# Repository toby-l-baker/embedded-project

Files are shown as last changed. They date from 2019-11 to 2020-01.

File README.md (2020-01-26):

# embedded-project
A semi-autonomous bike concept with the following goals
  1. Balance a model bicycle with a reaction flywheel.
  2. Drive the bike with a remote control and bluetooth.
  3. Implement state estimation to enable autonomous navigation.
  4. Setup a controller to send the bike to a target location.
  
## To see our final, integrated code base head to the Final Implementation folder in /software/apps

# Install
To use this repository first clone the directory. Following that run:
git submodule update --recursive --init

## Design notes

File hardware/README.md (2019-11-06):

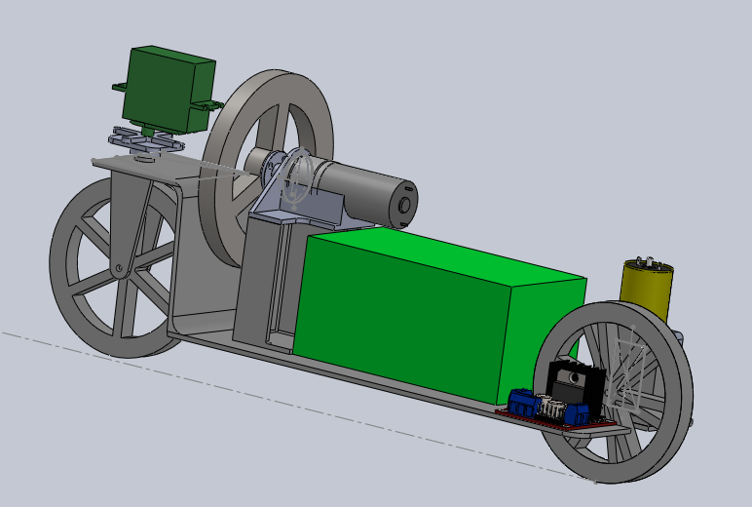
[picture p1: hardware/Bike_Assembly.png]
Bike

# Parts to Buy
## Driving Motor
https://www.amazon.com/dp/B071GX51N7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
## Flywheel Motor
https://www.pololu.com/product/4863
## Wheels
https://www.amazon.com/90-10mm-Black-Robot-Wheels/dp/B00T3MQG7M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
## Battery
https://www.amazon.com/TalentCell-Rechargeable-Amplifier-Multi-led-Indicator/dp/B00MHNQIR2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

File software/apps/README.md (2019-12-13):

# Instructions for fixing timer conflict: 
`ERROR 8 [NRF_ERROR_INVALID_STATE]`
### Edit line 25 of embedded-project/software/buckler/software/libraries/mpu9250/mpu9250.c to a new timer:
`static const nrf_drv_timer_t gyro_timer = NRFX_TIMER_INSTANCE(<X>);`
### Add the following definitions for the timer X in embedded-project/software/buckler/software/boards/buckler_revB/app_config.h:
`#define NRFX_TIMER<X>_ENABLED 1`<br />
`#define TIMER<X>_ENABLED 1`

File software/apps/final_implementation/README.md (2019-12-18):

# Final Implementation that was used on Demo Day

## Contents
1. accel_list: an adaptation of a linked list library found online used to store accelerometer readings to turn on brake lights
    * Author: Garey
2. bike_control_remote.py: bike_control is the file used from lab and bike_control_remote is an adaptation that uses the N64 remote joystick and various buttons to control the bike.
    * Author: Toby
3. board_params.h: contains all macros used throughout the code including pin numbers, constants etc.
4. control*: contains both the code used for estimation and control of the bike to it's desired location (app folder: self_driving)
   * Authors: Leo (Estimation), Carl (Control)
5. Madgwick*: a sensor fusion algorithm for the gyro and accelerometer of the mpu9250, this was sourced online and gave us reliable roll, pitch and yaw readings.
6. main: contains the state machine on the bike consisting of OFF, MANUAL and AUTONOMOUS modes as well as the BLE setup.
    * Author: Toby Baker
7. motor*: contains the functions to setup DC motors and write PWM values to them (app folder: motor_driver)
    * Author: Garey
8. mpu*: Contains all code relating to the mpu9250 including reading, filtering, SW interrupts.
    * Authors: Toby, Garey
9. servo_driver*: interface setting up and writing angles to the servo motor used for steering.
    * Authors: Carl, Leo
10. setup*: setup code for PWM channels used by each motors
    * Author: Garey
11. tail_lights*: code that controls the brake light and indicator lights on the bike, an essential safety feature of the sem-autonomous bike
    * Author: Garey
12. timer_module*: code for interfacing with the timer peripheral so that we could timestamp our angles, used for blinkers and estimation (as well as PID in balancing mode)
    * Author: Garey

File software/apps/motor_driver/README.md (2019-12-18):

# MOTOR DRIVER APP

## Contents
1. Initial app to interface with the motors

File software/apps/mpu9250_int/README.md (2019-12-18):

# MPU9250 App

## Contents
1. Initial app to interface with the MPU9250
2. Also initializes a timer to poll the sensor on SW interrupts

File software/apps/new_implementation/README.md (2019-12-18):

# Timers
MPU I2C:          1 <br />
Servo Motor PWM:  2 <br />
DC Motor PWM:     3 <br />
Timer Module:     4 <br />

## To Run project update repo: <br />
`git submodule update --init --recursive`
## Add the following macros to: <br /> 
`embedded-project/software/buckler/software/boards/buckler_revB/app_config.h`

`#define NRFX_TIMER0_ENABLED 1`<br />
`#define TIMER0_ENABLED 1`<br />
`#define NRFX_TIMER1_ENABLED 1`<br />
`#define TIMER1_ENABLED 1`<br />
`#define NRFX_TIMER2_ENABLED 1`<br />
`#define TIMER2_ENABLED 1`<br />
`#define NRFX_TIMER3_ENABLED 1`<br />
`#define TIMER3_ENABLED 1`<br />
`#define NRFX_TIMER4_ENABLED 1`<br />
`#define TIMER4_ENABLED 1`<br />

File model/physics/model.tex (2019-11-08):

\documentclass[11pt]{article}
\usepackage[utf8]{inputenc}
\usepackage[T1]{fontenc}
\usepackage[margin=0.75in]{geometry}
\usepackage{amsmath} 

\author{Léo Toulet, and I dont remember last names}
\date{Fall 2019}
\title{Flywheel stabilized self balancing bike - Physical modeling}

\begin{document}

\maketitle

\section{Lagrangian dynamics}

The objective of this document is to provide a physical model of a simple Bike system. Our objective is to to be able to balance such a bike even at low speeds, using a closed-loop flywheel to counter the action of gravity on the bike and maintain an upward position.
For this purpose, we define a simple model of our bike system, consisting of two main parts. 
\begin{itemize}
	\item The bike structure, containing the frame, battery, Buckler and wheels
	\item The Motor+Flywheel assembly, that actually balances the bike
\end{itemize}

\subsection{Definitions}

We define the intrinsic parameters of the bike structure as its mass $m_b$, its moment of inertia about its rotation axis (i.e. is the ground) $I_b$ and the height of its center of gravity $L_b$. Similarly, we define the mass of the motor,flywheel assembly to be $m_w$, its distance to the ground to be $L_w$ and the moment of inertia of the wheel around its rotation axis to be $I_w$. As far as the rotational motion of the bike+flywheel+motor structure is concerned, we consider the \{flywheel+motor\} to be a point. 

To define the Lagrangian of the system, we also need to define the generalized coordinates, which in our case are simple $\alpha$, the angle the bike makes with the vertical, and $\theta$, the angle the flywheel makes to some arbitrary reference point. We therefore have $$ q = [\alpha, \theta]$$. Finally, we define $F$ to be the generalized forces applied to our system, and we assume that \textit{there are no non-conservative forces}

%Insert diagram here

\subsection{Lagrangian}

Using our previous definitions, we define the Lagrangian function to be the following quantity $L(q,\dot{q}) = E(q, \dot{q}) - V(q, \dot{q})$. Here, E is the kinetic energy of the system and V is its potential energy. The Lagrangian satisfies the following equation: satisfies:

$$ \frac{d}{dt}\frac{\partial L}{\partial \dot{q}} - \frac{\partial L}{\partial q} = F$$ 

\subsection{Energies}

We will begin with the the potential energy. The only potential energy applied on the system comes from the weight. Therefore, we have $V(q, \dot{q}) = (m_w L_w + m_b L_b)g\sin(\alpha)$. Here, we will only consider small inclinations of the bike $\alpha << \pi/6$, and we can reasonably make the approximation that the sine is equal to its argument, transforming our potential energy into 

$$V(q, \dot{q}) = (m_w L_w + m_b L_b)g\alpha$$

The kinetic energy has three terms. The first two account for the kinetic energy of the global rotation of the system around the ground axis. The last term accounts for the rotation of the wheel around the motor axis.

$$E(q, \dot{q}) = \frac{1}{2}\left[I_p \dot{\alpha}^2 + m_w L_w^2 \dot{\alpha}^2 + I_w \dot{\theta}^2)\right]$$

Finally, $F$ is the vector of generalized forces that apply on the system, which in our case is simply defined as:

$$F = [-I_w \ddot{\alpha}, \tau - I_w \ddot{\theta}]$$

\subsection{System dynamics}

Working through the differentiation, we arrive at the following coupled equations: 

$$I_s \ddot{\alpha} + I_w\ddot{\theta} = \tau_\alpha \alpha$$
$$I_w(\ddot{\alpha} + \ddot{\theta}) = \tau$$

Where $\tau_\alpha  = (m_b L_b + m_w L_w)g$ and $ I_s= I_b + m_w*L_w^2$

\section{System specifications}

Using the previous coupled equations, we want to find the minimum motor and flywheel specifications for our self-balancing bike to work. To do that, we will make a couple of assumptions:

\begin{center}
\begin{tabular}{|c|rl|}
\hline
Variable & Value & Unit \\
\hline
\hline

$L_w$ & $10$ & $cm$ \\
$L_b$ & $5$ & $cm$ \\
$m_w$ & $600$ & $g$ \\
$m_b$ & $1000$ & $g$ \\
$I_b$ & $5 10^{-3}$ & $kgm^2$ \\
$I_w$ & $9 10^{-5}$ & $kgm^2$ \\
\hline
\end{tabular}
\end{center}

Using those vales, we get $\tau_\alpha = 3 Nm$ and $I_s = 1.1 10^{-2} kgm^2$. Assuming we want alpha to remain within 4 degrees of the vertical, we define $\alpha_{max} = 0.07$ rad.

\subsection{Flywheel motor}

The dynamics equations can be coupled to give:

$$\ddot{\alpha} = \frac{\tau_\alpha \alpha - \tau}{I_s + I_w}$$

Correcting an imbalance means correcting the sign of $\ddot{\alpha}$ to make it opposite to that of $\alpha$. That is, if we want our system to be able to be able to correct positioning errors, we want:

$$|\tau| > |\tau_\alpha \alpha_{max}|$$

i.e. :

$$|\tau| > 0.2 Nm$$

\subsection{Flywheel moment of inertia}

\end{document}

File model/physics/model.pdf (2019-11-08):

## Flywheel stabilized self balancing bike - Physical modeling

Léo Toulet, and I dont remember last names

Fall 2019

## 1 Lagrangian dynamics

The objective of this document is to provide a physical model of a simple Bike system. Our objective is to to be able to balance such a bike even at low speeds, using a closed-loop ywheel to counter the action of gravity on the bike and maintain an upward position. For this purpose, we dene a simple model of our bike system, consisting of two main parts.

- The bike structure, containing the frame, battery, Buckler and wheels
- The Motor+Flywheel assembly, that actually balances the bike

1.1 Denitions

We dene the intrinsic parameters of the bike structure as its mass mb, its moment of inertia about its rotation axis (i.e. is the ground) Ib and the height of its center of gravity Lb. Similarly, we dene the mass of the motor,ywheel assembly to be mw, its distance to the ground to be Lw and the moment of inertia of the wheel around its rotation axis to be Iw. As far as the rotational motion of the bike+ywheel+motor structure is concerned, we consider the {ywheel+motor} to be a point.
To dene the Lagrangian of the system, we also need to dene the generalized coordinates, which in our case are simple α, the angle the bike makes with the vertical, and θ, the angle the ywheel makes to some arbitrary reference point. We therefore have

q = [α, θ]

. Finally, we dene F to be the generalized forces applied to our system, and we assume that there are no non-conservative forces

1.2 Lagrangian

Using our previous denitions, we dene the Lagrangian function to be the following quantity L(q, q˙) = E(q, q˙) − V (q, q˙). Here, E is the kinetic energy of the system and V is its potential energy. The Lagrangian satises the following equation: satises:

d
dt

∂L
∂q˙

−

∂L
∂q = F

1.3 Energies

We will begin with the the potential energy. The only potential energy applied on the system comes from the weight. Therefore, we have V (q, q˙) = (mwLw + mbLb)g sin(α). Here, we will only consider small inclinations of the bike α << π/6, and we can reasonably make the approximation that the sine is equal to its argument, transforming our potential energy into

1

V (q, q˙) = (mwLw + mbLb)gα

The kinetic energy has three terms. The rst two account for the kinetic energy of the global rotation of the system around the ground axis. The last term accounts for the rotation of the wheel around the motor axis.

E(q, q˙) = 1
2

h
Ipα˙

2 + mwL

2
wα˙

2 + Iw

˙θ
2
)

i

Finally, F is the vector of generalized forces that apply on the system, which in our case is simply dened as:

F = [−Iwα, τ ¨ − Iw

¨θ]

1.4 System dynamics

Working through the dierentiation, we arrive at the following coupled equations:

Isα¨ + Iw

¨θ = ταα

Iw(¨α + ¨θ) = τ

Where τα = (mbLb + mwLw)g and Is = Ib + mw ∗ L

2
w

## 2 System specications

Using the previous coupled equations, we want to nd the minimum motor and ywheel specications for our self-balancing bike to work. To do that, we will make a couple of assumptions:

Variable | Value Unit
Lw Lb mw mb Ib Iw | 10 cm 5 cm 600 g 1000 g 510⁻³ kgm² 910⁻⁵ kgm²

Using those vales, we get τα = 3Nm and Is = 1.110⁻²kgm² . Assuming we want alpha to remain within 4 degrees of the vertical, we dene αmax = 0.07 rad.

2.1 Flywheel motor

The dynamics equations can be coupled to give:

α¨ =

ταα − τ
Is + Iw
Correcting an imbalance means correcting the sign of α¨ to make it opposite to that of α. That is, if we want our system to be able to be able to correct positioning errors, we want:
|τ | > |τααmax|

i.e. :

|τ | > 0.2Nm

2

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

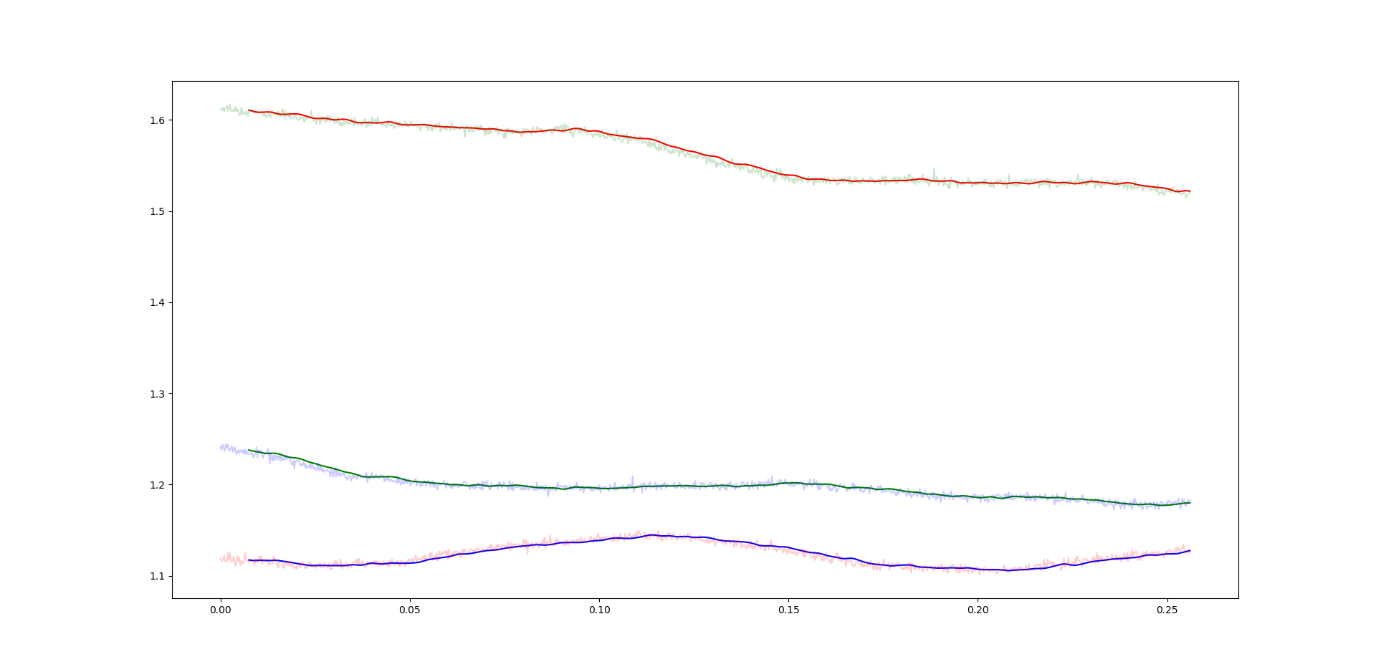
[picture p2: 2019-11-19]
software/apps/signal_processing/XYZ_Filtered.png

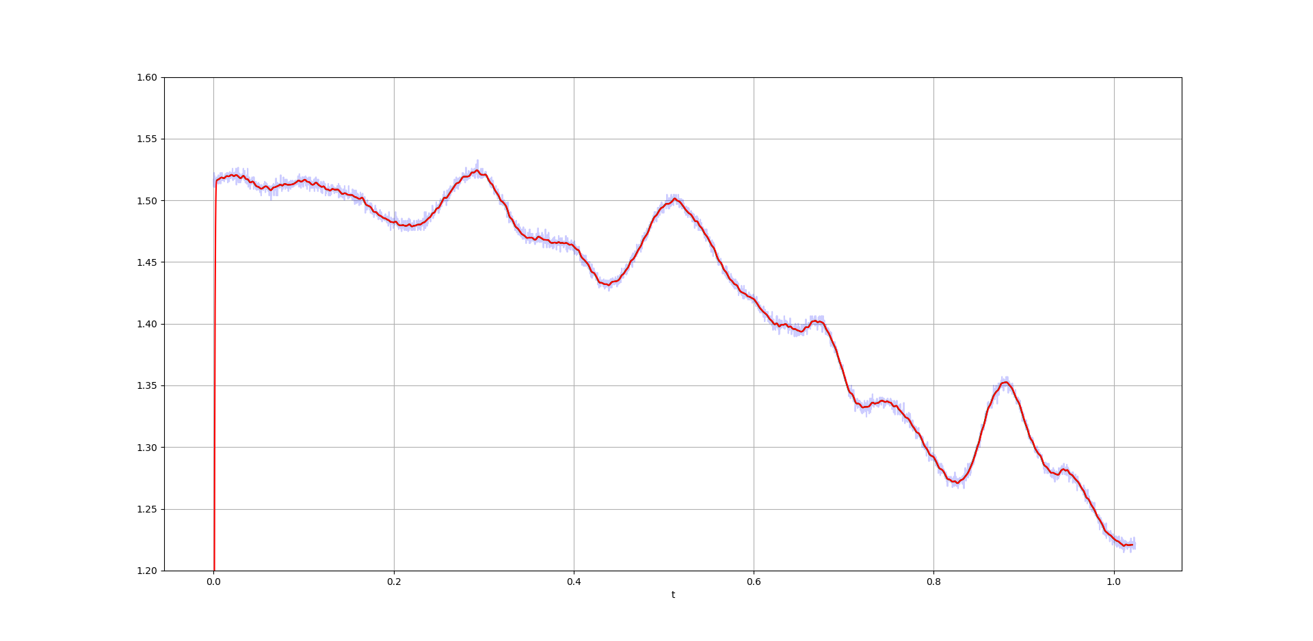
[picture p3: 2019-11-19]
software/apps/signal_processing/X_Filtered.png

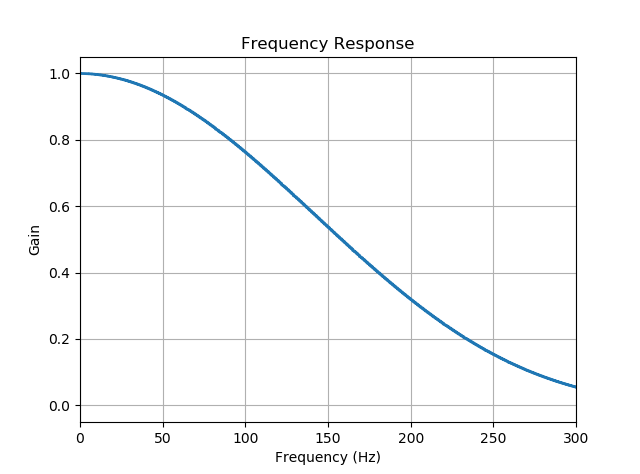
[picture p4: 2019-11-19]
software/apps/signal_processing/Freq_Response.png

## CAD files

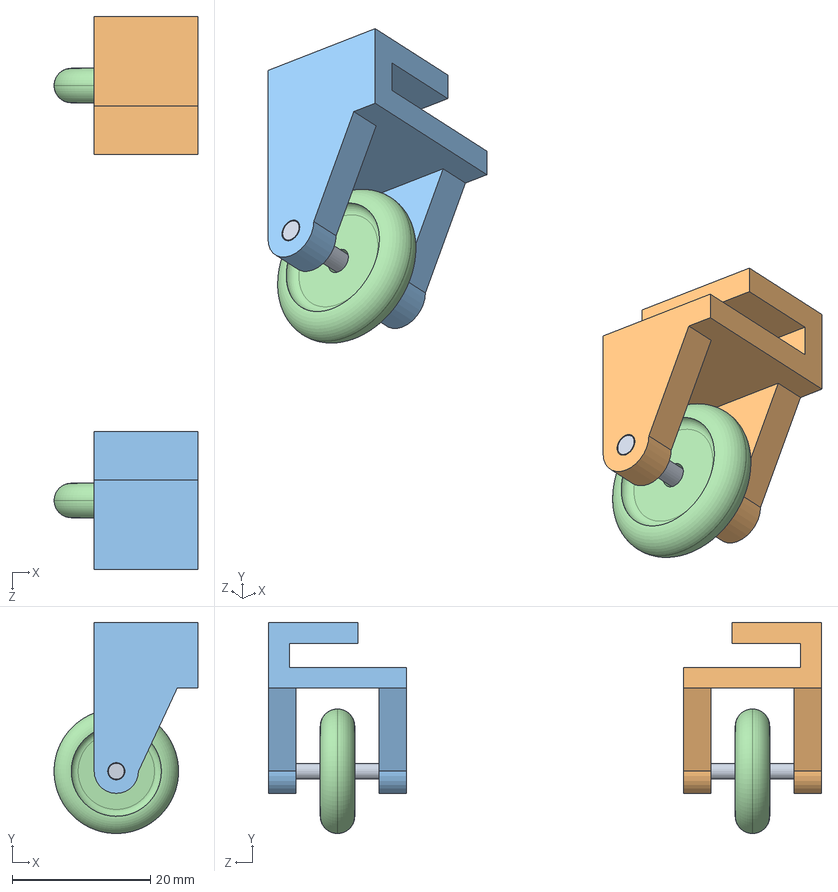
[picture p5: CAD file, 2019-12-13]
hardware/Caster_Assembly_Left.SLDASM
20.8 x 30.5 x 80.0 mm
Caster_Wheel_Axle x 2
Caster_Wheel_Holder_Mirror
Caster_Wheel_Holder
Caster_Wheel x 2

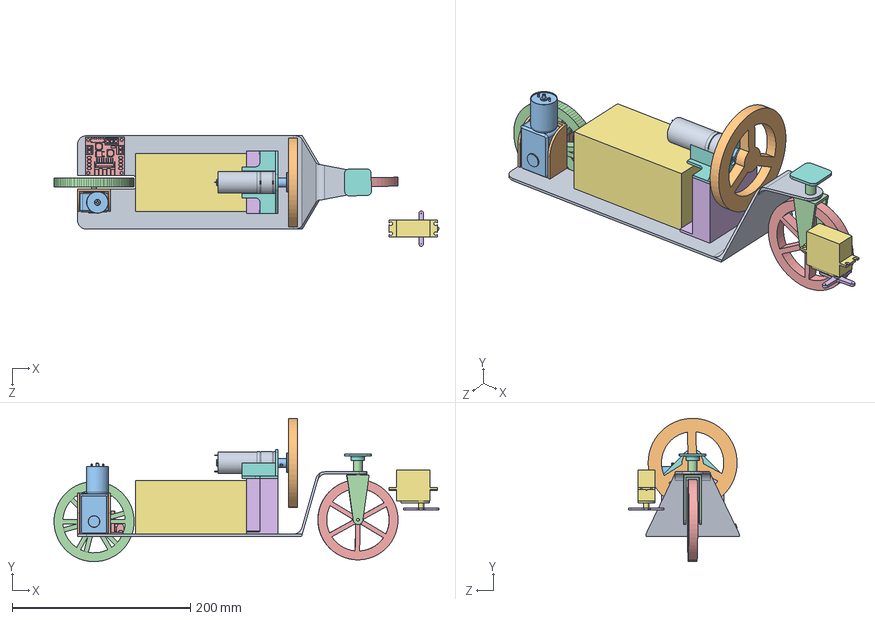
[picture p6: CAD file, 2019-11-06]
hardware/Bike_Assembly.SLDASM
432.5 x 160.9 x 124.4 mm
Bike_Base
Drive_Motor_Holder
Drive_Motor
Basic_Wheel_Model (1) x 2
L298N
Flywheel_Motor_Holder_Base
Buckler_Place_Holder
Flywheel_Motor_Holder
Flywheel_Motor
Flywheel
Flywheel_coupler
Front_Fork
Basic_Wheel_Model
Servo_Plate
servo_motor
Servo_Front_Fork_Connector

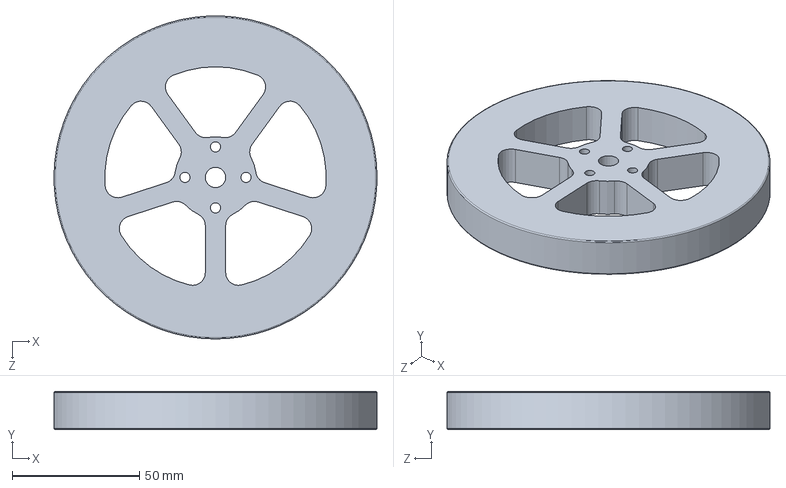
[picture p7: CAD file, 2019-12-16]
hardware/Final_Flywheel.SLDPRT
127.0 x 15.0 x 126.9 mm

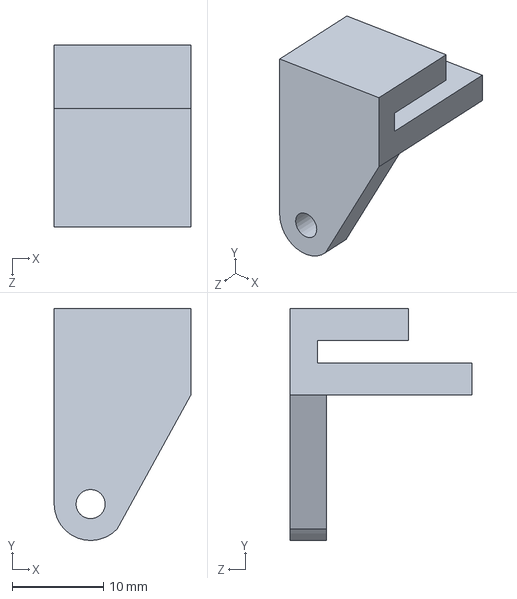
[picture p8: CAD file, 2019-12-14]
hardware/Caster_Wheel_Holder.SLDPRT
15.0 x 25.5 x 20.0 mm

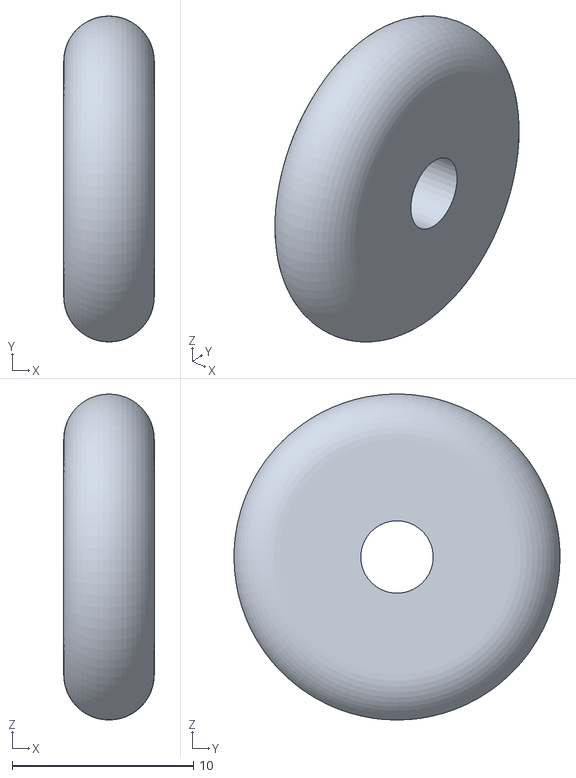
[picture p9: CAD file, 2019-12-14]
hardware/Manufacturing Files/Caster_Wheel.STL
5.00 x 18.0 x 18.0

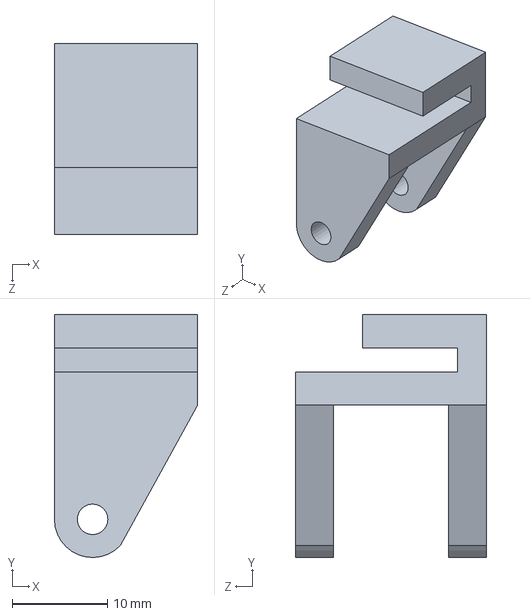
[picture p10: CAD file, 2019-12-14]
hardware/Caster_Wheel_Holder_Mirror.SLDPRT
15.0 x 25.5 x 20.0 mm

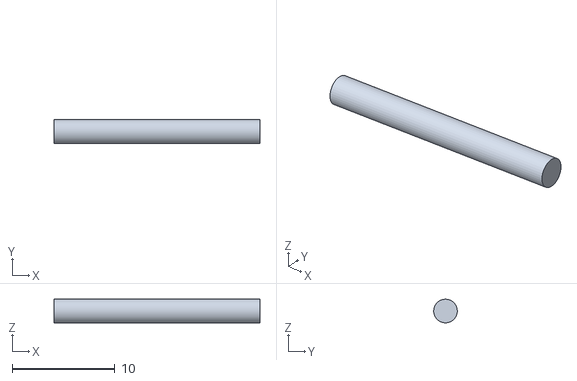
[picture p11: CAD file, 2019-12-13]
hardware/Manufacturing Files/Caster_Wheel_Axle.STL
20.0 x 2.30 x 2.30

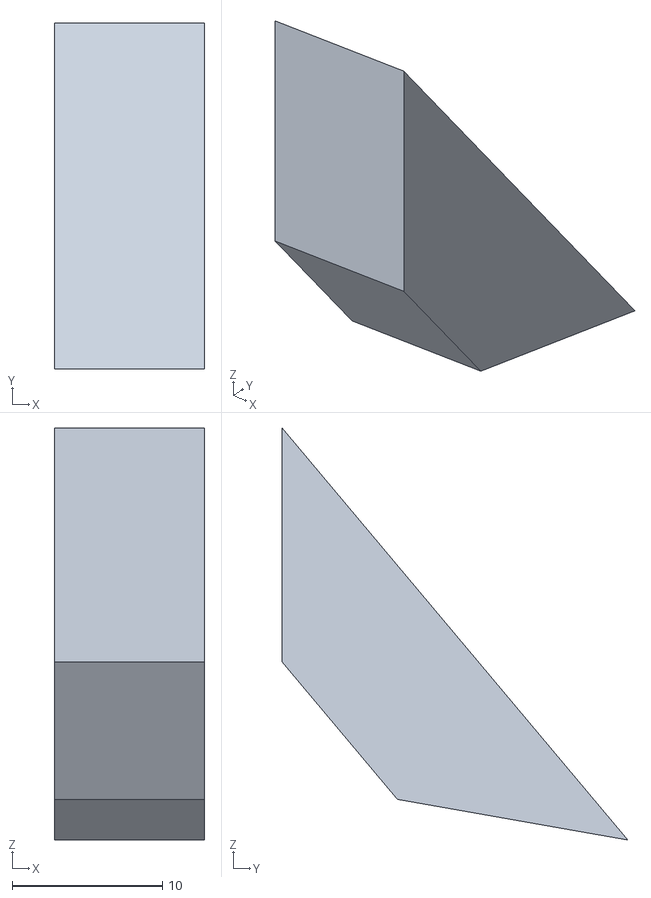
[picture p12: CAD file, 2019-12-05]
hardware/Manufacturing Files/Upper_Gusset.STL
10.0 x 23.0 x 27.4

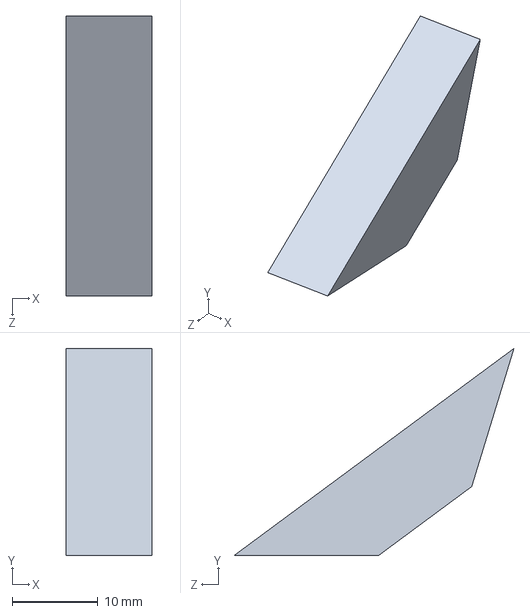
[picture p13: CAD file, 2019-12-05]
hardware/Lower_Gusset.SLDPRT
10.0 x 24.1 x 32.6 mm

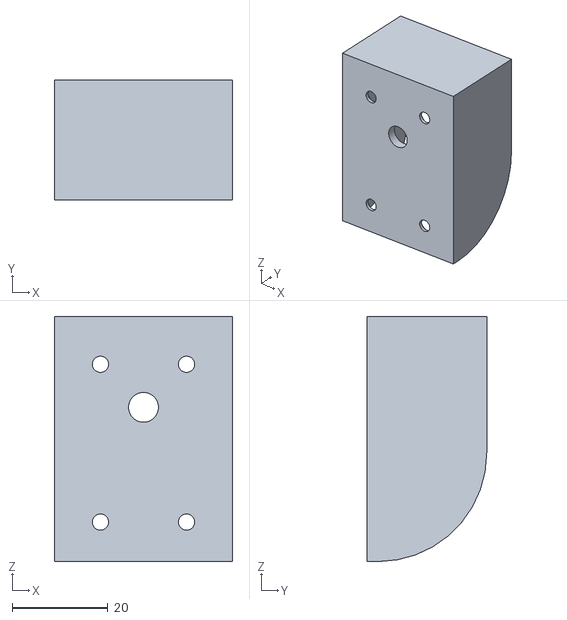
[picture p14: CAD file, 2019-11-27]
hardware/Manufacturing Files/Drive_Motor_Holder.stl
37.2 x 25.0 x 51.2

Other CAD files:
hardware/Manufacturing Files/Final_Flywheel.stl
hardware/Caster_Wheel.SLDPRT
hardware/Manufacturing Files/Caster_Wheel_Holder.STL
hardware/Manufacturing Files/Caster_Wheel_Holder_Mirror.STL
hardware/Caster_Wheel_Axle.SLDPRT
hardware/Manufacturing Files/Lower_Gusset.STL
hardware/Upper_Gusset.SLDPRT
hardware/Flywheel_3DPrinter.SLDPRT
hardware/Basic_Wheel_Model.SLDPRT
hardware/Bike_Base.SLDPRT
hardware/Buckler_Place_Holder.SLDPRT
hardware/Drive_Motor.SLDPRT
hardware/Drive_Motor_Holder.SLDPRT
hardware/Flattened_Base.DXF
hardware/Flattened_Base.SLDPRT
hardware/Flywheel.SLDPRT
hardware/Flywheel_Motor.SLDPRT
hardware/Flywheel_Motor_Holder.SLDPRT
hardware/Flywheel_Motor_Holder_Base.SLDPRT
hardware/Flywheel_coupler.SLDPRT
hardware/Front_Fork.SLDPRT
hardware/L298N.SLDPRT
hardware/Manufacturing Files/Bike_Base.stl
hardware/Manufacturing Files/Flywheel_3DPrinter.stl
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

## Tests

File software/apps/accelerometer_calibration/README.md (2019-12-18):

# Accelerometer Calibration App
### Author: Toby Baker

## Contents
1. slist: an implementation of a linked list found online used to store 30 readings which will then be passed to an FIR filter
2. virtual_timer libraries: virtual timer linked list from lab to get regular samples from the accelerometer
3. main: contains an implementation of an FIR filter applied to each channel of the analog accelerometer
4. Various .txt files containing the output of the analog accelerometer

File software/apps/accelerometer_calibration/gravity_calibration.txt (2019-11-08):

Vcc = ?

+1g Z: 1.8040 V
-1g Z: 1.0224 V
0g Z: 1.3950 V

V(+1g) = z_bias + 1g * z_gain
V(-1g) = z_bias - 1g * z_gain

2.8264 = 2*z_bias
z_bias = 1.4132 V
z_gain = 1.8040 - 1.4132 = 0.3908 V/g

+1g Y: 1.7878 V
-1g Y: 1.0140 V
0g Y: 1.4075 V

y_bias = 1.4009 V
y_gain = 0.3869 V/g

+1g X: 1,7840 V
-1g X: 1.0242 V
0g X: 1.3830 V

x_bias = 1.4041 V
x_gain = 0.3799 V/g

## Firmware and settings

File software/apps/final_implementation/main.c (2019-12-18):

/*** Final Implementation of the Semi-Autonomous Bike Demo ***/

#include "setup.h" // includes all libraries we use

/* Function for printing the state that the bike is in for debugging ***/
void print_state(bike_states current_state){
	switch(current_state){

  	case OFF: {
  		printf("Off\n");
  		break;
    }

    case MANUAL: {
  		printf("Manual\n");
  		break;
    }

    case AUTONOMOUS: {
  		printf("Autonomous\n");
  		break;
    }

  }
}

int main(void) {
	float x, y, heading, turn_auto = 0.0; // variables for the current x, y and heading of the bike
	bool destination_set = false;

  // setup the board
  initialize_buckler();
  // setup BLE
  init_ble_receiver();

	// setup the servo
	struct servo * front = create_servo(SERVO_PIN, PWM_CHANNEL_0);
  initialize_servo_motor_pwm(front);

  // setup the drive motor and flywheel
	struct dc_motor * drive = create_dc_motor(DRIVE_PIN_ENABLE, DRIVE_PIN_IN1, DRIVE_PIN_IN2, DRIVE_MOTOR_CHANNEL);
  int8_t direction = STOP; // direction for the drive motor
  struct dc_motor * flywheel = create_dc_motor(FLYWHEEL_PIN_ENABLE, FLYWHEEL_PIN_IN1, FLYWHEEL_PIN_IN2, FlYWHEEL_MOTOR_CHANNEL);
	initialize_dc_motor_pwm(drive, flywheel);

  // setup the mpu9250 software interrupts and the sensor (I2C etc.)
  bool ble = true; // to avoid double initializing app_timer
  init_mpu9250_timer(IMU_TIMER_REFRESH_RATE, ble);
  init_mpu9250();

  // setup the angles struct - struct in mpu.h
  struct angles_t * angles = malloc(sizeof(angles_t));
  angles->heading = 0.0;

  // setup tail lights (initializes the display)
  init_tail_lights();

  // initialise the tracking by giving it a pointer to drive motor, servo motor and the angles struct
  init_tracking(drive, front, angles);

  // begin tracking the bikes position
  start_tracking();

	// loop forever, running state machine
  printf("Entering Main\n");

  // used to print less often
  int i = 0;

	while (1) {
    // update the angles struct (internally checks if the timer has fired)
    update_angles(angles);

    // update the blinkers on the LCD screen
    update_lights(angles);

    /*** STATE MACHINE ***/
    switch(bike_state) { // state transitions handled by the callback function for BLE events
      /*** BIKE OFF ***/
      case OFF: {
        print_state(bike_state);
        break; // each case needs to end with break!
      }

      /*** MANUAL CONTROL OF THE BIKE ***/
      case MANUAL: {
        print_state(bike_state);

        // set servo angle to the user defined angle (from joystick)
        set_servo_angle(front, (float) turn_angle);

        // set the bikes direction based off the drive_speed
        if (drive_speed == 0){
          direction = STOP;
        } else if (drive_speed > 0) {
        	direction = FORWARD;
        } else {
          direction = REVERSE;
        }
        // send values to the drive_motor
        set_dc_motor_direction(drive, direction);
    	  set_dc_motor_pwm(drive, drive_speed);

        // print debug info every 20 loops
        if (i++ % 20 == 0) {
          printf("%f\n", angles->time_stamp);
        }
        break;
      }

      /*** AUTONOMOUS CONTROL OF THE BIKE ***/
      case AUTONOMOUS: {
        print_state(bike_state);
        // Wait until our path is defined or we have accomplished our goal
        if ((path_angle_received == false) || (path_len_received == false) || (nav_complete == true)) {
          direction = STOP;
          drive_speed = 0;
          turn_auto = 0;
          // printf("IM DOING NOTHING: nav %d, len: %d, ang: %d\n", nav_complete, path_len_received, path_angle_received);
          // ensures the gyro is reset before we start navigation
          mpu9250_stop_gyro_integration();
        } else {
          /*** GET TO OUR GOAL LOCATION ***/
          if (destination_set == false) { // only set our destination once
            reset_tracking(); // reset our initial position (function in control.c)
            mpu9250_start_gyro_integration(); // begin integrating gyro to track our heading
            printf("Angle:%d, Length:%d\n", path_angle, path_len);  // print the polar coords the bike was given
            set_dest(path_len, path_angle); // set the bikes destination
            destination_set = true;
          }

          angles->heading = mpu9250_read_gyro_integration().z_axis; // update the heading
          direction = FORWARD;
          drive_speed = 100; // set PWM to 100
          turn_auto = calc_steering(); // find the steering angle determined by control

          // every 20 loops print current state and turn command
          if (i++ % 20 == 0) {
            printf("x: %f, y %f, heading: %f, turn angle: %f\n", x, y, heading, turn_auto);
          }
        }
        // set drive motor and sero angle to desired angles and speed
        set_dc_motor_direction(drive, direction);
        set_dc_motor_pwm(drive, drive_speed); // always drive at a constant speed in auto mode
        set_servo_angle(front, turn_auto);
        break;
      }
    }
    nrf_delay_ms(1);
	}
}

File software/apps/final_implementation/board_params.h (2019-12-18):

#ifndef BOARD_PARAMS_H
#define BOARD_PARAMS_H

#include "setup.h"

/*** Angle Conversion Parameters ***/
#define TO_RAD 0.0174532925 // PI / 180
#define TO_DEG 57.2957795131 // 180 / PI
#define PI 3.1415926535

/*** Estimation Parameters ***/
#define TO_M 0.01
#define VX 0.285 // velocity of the bike at 100 PWM

/***Servo Parameters***/
#define SERVO_RANGE 170
#define MAX_TURN_ANGLE 45
#define SERVO_PIN NRF_GPIO_PIN_MAP(0,27)
#define SERVO_MOTOR_TIMER		1
#define SERVO_MOTOR_CHANNEL		0
#define SERVO_MOTOR_FREQ		20000L

/*** BLINKER PARAMETERS ***/
#define RIGHT 1
#define LEFT -1
#define RIGHT_BLINKER_STRING	"              >>"
#define LEFT_BLINKER_STRING		"<<              "
#define BRAKE_STRING			"|||          |||"
#define BOTH_BLINKER_STRING		"<<            >>"
#define EMPTY_STRING			"                "
#define ACCEL_POSITIVE 1
#define ACCEL_NEGATIVE -1
#define ACCEL_ZERO		0
#define BLINKER_SAMPLE_FREQ 50
#define MICROSECONDS 1000000.0

/***BLINKER PARAMS***/
#define BRAKE_ACCELERATION_USECOND_THRESH 60000.0
#define BRAKE_ACCEL_THRESHOLD_VAL_G			0.12
#define BLINKER_PERIOD	0.25
#define MINIMUM_BLINKER_ANGLE_PER_USECOND 0.000003

/*** Defines for directions used in set_dc_motor_direction() ***/
#define FORWARD				1
#define REVERSE				-1
#define STOP				0

/*** CONTROL PARAMETERS ***/
#define CONTROL_GAIN 4.0

/*** ESTIMATION PARAMETERS ***/
#define DRIVE_RPM_PER_PWM 0.420 //The number of RPM per unit of PWM, assuming a linear relationship
#define WHEEL_RADIUS_M 0.045
#define TRACKING_UPDATE_MS 10.0
#define BIKE_LENGTH_M 0.30

/*** TIMER PARAMETERS ***/
#define TIMER_MODULE_TIMER 		4

/*** GPIO PINS USED FOR MOTORS ***/
#define FLYWHEEL_PIN_ENABLE NRF_GPIO_PIN_MAP(0,11)
#define FLYWHEEL_PIN_IN1 NRF_GPIO_PIN_MAP(0,12) // 26
#define FLYWHEEL_PIN_IN2 NRF_GPIO_PIN_MAP(0,13) //2
#define DRIVE_PIN_ENABLE NRF_GPIO_PIN_MAP(0,3)
#define DRIVE_PIN_IN1 NRF_GPIO_PIN_MAP(0,4)
#define DRIVE_PIN_IN2 NRF_GPIO_PIN_MAP(0,28)

/***DC MOTOR PARAMETERS***/
#define DC_MOTOR_TIMER			1
#define DC_MOTOR_FREQ			5000L
#define FLYWHEEL_MOTOR_CHANNEL	1
#define DRIVE_MOTOR_CHANNEL

/*** IMU PARAMS ***/
#define IMU_TIMER_REFRESH_RATE 1.9

#define NUM_LOOPS 100
#define PRESCALE_CONV 0.000001

#endif

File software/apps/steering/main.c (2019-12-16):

// Analog accelerometer app
//
// Reads data from the ADXL327 analog accelerometer

#include <stdbool.h>
#include <stdint.h>
#include <stdio.h>
#include <math.h>

#include "app_error.h"
#include "nrf.h"
#include "nrf_delay.h"
#include "nrf_gpio.h"
#include "nrf_log.h"
#include "nrf_log_ctrl.h"
#include "nrf_log_default_backends.h"
#include "nrf_pwr_mgmt.h"
#include "nrf_serial.h"
#include "nrfx_gpiote.h"
#include "app_pwm.h"

#include "buckler.h"
#include "servo_driver.h"


#define PIN_NB 27

/* Initialize PWM2 on TIMER 1 */
APP_PWM_INSTANCE(PWM2,1);

/* CODE RESOURCES */
// https://infocenter.nordicsemi.com/index.jsp?topic=%2Fcom.nordic.infocenter.sdk5.v12.0.0%2Flib_pwm.html
// https://infocenter.nordicsemi.com/index.jsp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
// https://github.com/xueliu/nRF52/blob/master/nRF52_SDK_0.9.1_3639cc9/components/libraries/pwm/app_pwm.h

int main (void) {
    ret_code_t error_code = NRF_SUCCESS;

    // initialize RTT library
    error_code = NRF_LOG_INIT(NULL);
    APP_ERROR_CHECK(error_code);
    NRF_LOG_DEFAULT_BACKENDS_INIT();

    // initialization complete
    printf("Buckler initialized!\n");
    // printf("%d\n", (uint8_t) ((-50.0+90.0)*9.0/180.0 + 1.0));
    /* Create Motor Structs */

	// nrf_gpio_pin_set(drive->enable);

	// while(1){
	// 	nrf_delay_ms(25);
	// }



    struct servo * front = create_servo(PIN_NB, PWM_CHANNEL_0, &PWM2);

    /* Initialize 1 CH PWM, 50 Hz */
    app_pwm_config_t pwm_cfg = APP_PWM_DEFAULT_CONFIG_1CH(20000L, front->pin_nb);

    /* Switch the polarity of the first channel. */
    pwm_cfg.pin_polarity[0] = APP_PWM_POLARITY_ACTIVE_HIGH;

    error_code = app_pwm_init(&PWM2, &pwm_cfg, pwm_ready_callback);
    APP_ERROR_CHECK(error_code);
    app_pwm_enable(&PWM2);

    /* Set both duty cycles to zero initially, wait until channels are ready */
    //while (app_pwm_channel_duty_set(&PWM0, 0, flywheel->duty_cycle) == NRF_ERROR_BUSY);
    printf("Enter main loop");

    uint8_t duty_cycle;
    // loop forever
    while(1) {
      // for(int i=0; i < 20; i++) {
      //   set_servo_pwm(front, i);
      //   printf("%d\n", i);
      //   nrf_delay_ms(1000);
      // }
      // for(int i=20; i > 0; i--) {
      //   set_servo_pwm(front, i);
      //   printf("%d\n", i);
      //   nrf_delay_ms(1000);
      // }

  //    set_servo_pwm(front, (13));
   //   printf("13\n");
    //  nrf_delay_ms(1000);

   //   set_servo_pwm(front, (11/2 + 2));
   //   nrf_delay_ms(1000);
   //   printf("7.5\n");

     set_servo_angle(front, (0));
     nrf_delay_ms(5000);

      set_servo_angle(front, (45));
      nrf_delay_ms(5000);
      //printf("145\n");

      set_servo_angle(front, (0));
      nrf_delay_ms(5000);
      //printf("7.5\n");

      set_servo_angle(front, (-45));
      nrf_delay_ms(5000);
      //printf("13\n");
    }
}

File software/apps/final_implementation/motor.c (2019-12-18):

#include "setup.h"

struct dc_motor * create_dc_motor(uint8_t enable, uint8_t in1, uint8_t in2, uint8_t pwm_channel){
    struct dc_motor * motor = malloc(sizeof(struct dc_motor));
    if (motor) {
        // nrf_gpio_cfg_output(enable);
        nrf_gpio_cfg_output(in1);
        nrf_gpio_cfg_output(in2);
        // nrf_gpio_pin_clear(enable);
        nrf_gpio_pin_clear(in1);
        nrf_gpio_pin_clear(in2);
        motor->duty_cycle = 0;
        motor->enable = enable;
        motor->in1 = in1;
        motor->in2 = in2;
        motor->pwm_channel = pwm_channel;
    }
    return motor;

}

void set_dc_motor_direction(struct dc_motor * motor, int8_t direction){
    motor->direction = direction;
    switch(direction){
        case FORWARD:
            // printf("Setting direction to forward.\n");
            nrf_gpio_pin_set(motor->in1);
            nrf_gpio_pin_clear(motor->in2);
            break;
        case REVERSE:
            // printf("Setting direction to reverse.\n");
            nrf_gpio_pin_set(motor->in2);
            nrf_gpio_pin_clear(motor->in1);
            break;
        case STOP:
            // printf("Setting direction to stop.\n");
            nrf_gpio_pin_clear(motor->in1);
            nrf_gpio_pin_clear(motor->in2);
            break;
        default:
            // printf("ERROR: incorrect motor direction\n");
            break;
    }
}

ret_code_t set_dc_motor_pwm(struct dc_motor * motor, uint8_t duty_cycle){
    motor->duty_cycle = duty_cycle;
    return app_pwm_channel_duty_set(motor->pwm_inst, motor->pwm_channel, motor->duty_cycle);
    // while (app_pwm_channel_duty_set(motor->pwm_inst, motor->pwm_channel, motor->duty_cycle) == NRF_ERROR_BUSY);
}


ret_code_t set_drive_PWM(struct dc_motor* motor, int8_t PWM) {

    ret_code_t error;

    if (PWM > 100) {PWM = 100;}
    if (PWM < -100) {PWM = - 100;}

    printf("Setting PWM to %d\n", PWM);

    if (PWM == 0) {
        set_dc_motor_direction(motor, STOP);
        error = set_dc_motor_pwm(motor, 0);
    }

    if (PWM < 0) {
        set_dc_motor_direction(motor, REVERSE);
        error = set_dc_motor_pwm(motor, -PWM);
    }

    if (PWM > 0) {
        set_dc_motor_direction(motor, FORWARD);
        error = set_dc_motor_pwm(motor, PWM);
    }

    return error;
}

ret_code_t set_drive_speed(struct dc_motor* motor, float speed) {
    float PWM_float = speed / WHEEL_RADIUS_CM * 60.0 / (2 * PI * DRIVE_RPM_PER_PWM);

    if (PWM_float > 100.0 || PWM_float < -100.0) {
        printf("Required speed (%f cm/s) is more than max speed\n", speed);
    }

    int8_t PWM = (int8_t) PWM_float;

    if (PWM > 100) {PWM = 100;}
    if (PWM < -100) {PWM = - 100;}

    printf("Setting PWM to %d\n", PWM);

    ret_code_t error;

    if (PWM == 0) {
        set_dc_motor_direction(motor, STOP);
        error = set_dc_motor_pwm(motor, 0);
    }

    if (PWM < 0) {
        set_dc_motor_direction(motor, REVERSE);
        error = set_dc_motor_pwm(motor, -PWM);
    }

    if (PWM > 0) {
        set_dc_motor_direction(motor, FORWARD);
        error = set_dc_motor_pwm(motor, PWM);
    }

    return error;
}

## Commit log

2019-11-01 Cloned buckler repo and can compile our own code, also finished code for logging and calibrating the accelerometer
2019-11-03 Created SLDPRT for motorcycle base
    [Bike_Base.SLDPRT]
2019-11-03 SLDPRT design for DC motors
    Motors used for flywheel and back wheel control
    [Motor_no_shaft.SLDPRT]
2019-11-03 Filter design validated with 50 coefficients for 4 sets of data
2019-11-05 Replaced Bike Base design
    Finished design
    [Bike_Base.SLDPRT]
2019-11-05 Update README.md
    Changed drive motor
2019-11-05 Added most of the files
    There is a solid assembly, but it is not finished.
    [Basic_Wheel_Model.SLDPRT, Bike_Assembly.SLDASM, Bike_Base.SLDPRT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]
2019-11-05 Delete Motor_no_shaft.SLDPRT
    This motor is no longer being used
    [Motor_no_shaft.SLDPRT]
2019-11-05 New log files for testing the performance of the FIR filter and linked list buffer works as expected
2019-11-05 Filter imlementation confirmed by plotting results in Python, Sslightly slow to respond to changes input, consider adjusting filter design
2019-11-06 Finished Most files and updated the bike assembly
    The only part remaining to design connects the bike_base to the servo motor to drive the front wheel.
    [Bike_Assembly.SLDASM, Bike_Base.SLDPRT, Buckler_Place_Holder.SLDPRT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]
2019-11-06 Changed Bike_Base
    [Bike_Base.SLDPRT]
2019-11-07 New Hardware Files for Laser Cutting and Printing
    [Bike_Base.stl, Drive_Motor_Holder.stl, Flattened_Base.DXF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]
2019-11-07 New STL for the fork
    [Front_Fork.stl]
2019-11-08 Accelerometer calibrated and angle calculations included - Pitch represents control input
2019-11-08 First commit physics, motor specs
2019-11-15 New STL for 3D printed flywheel
    [Flywheel_3DPrinter.stl]
2019-11-15 New motor_driver directory
2019-11-15 motor_driver pwm code complete needs to be updated with logic for driving motors forward/backward
2019-11-15 First PID commit
2019-11-16 Helper functions for PID
2019-11-16 First PID version
2019-11-16 Added main to test pid
2019-11-16 Added prop controller
2019-11-16 Added accelerometer reading app
2019-11-16 PID working on balacing demo
2019-11-18 Motor driver h and c, not yet working
2019-11-18 Timer problem
2019-11-19 Split motor driver in .c and .h
2019-11-19 New bike base and fork w/ servo mount
    [Flattened_Base.DXF, Flattened_Base.SLDPRT, Front_Fork.SLDPRT]
2019-11-19 Added new folder (combined_implementation) with all modules together. Everything works except the reverse. A little slow in reaction time, and only proportional implemented right now.
    [accelerometer_reading.c, main.c, motors.c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]
2019-11-19 Extended height .25cm and added base.
    [Drive_Motor_Holder.SLDPRT]
2019-11-19 Laser cutting file for base and new front fork STL
    [Front_Fork.stl]
2019-11-19 Changed pin numbers, and main logic.
2019-11-22 BLE file complete, awaiting testing in lab with the buckler
2019-11-26 Removed about 60% of mass by cutting out spokes.
    [Flywheel_3DPrinter.SLDPRT]
2019-11-27 New flywheel and drive motor stl files
    [Drive_Motor_Holder.stl, Flywheel_3DPrinter.stl]
2019-12-03 Started new folder with board_params.h and files moved to easier to find locations. Cannot get PWM to work even though code is the same.
2019-12-04 filtering, and all setup are complete. Now considering different filtering or sensor.
2019-12-04 new main using sensor fusion for gyro and accelerometer
2019-12-05 new gussets
    [Lower_Gusset.SLDPRT, Upper_Gusset.SLDPRT]
2019-12-05 gusset stl files
    [Lower_Gusset.STL, Upper_Gusset.STL]
2019-12-09 Started servo implementation
2019-12-10 Worked on steering, can control position with duty cycle.
2019-12-11 Added set_angle to Servo Driver
2019-12-11 path planner memory issue
    [main.c]
2019-12-12 integrated servo with BLE code and removed unecessary libraries
2019-12-13 minor edits to main to use timer3
2019-12-13 Get PID compiling, still need to test.
2019-12-13 Caster Wheel SLDPRT Files
    [Caster_Assembly_Left.SLDASM, Caster_Wheel.SLDPRT, Caster_Wheel_Axle.SLDPRT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]
2019-12-13 Caster Wheel 3D Printing Files
    [Caster_Wheel.STL, Caster_Wheel_Axle.STL, Caster_Wheel_Holder.STL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]
2019-12-13 Added driving and speed calibration functions, todo integrate speed to get distance value
2019-12-13 calibrated servo motor
2019-12-13 removed almost all code to test IMU
2019-12-13 added sensor files to main implementation
2019-12-13 new caster stl's
    [Caster_Wheel.STL, Caster_Wheel_Holder.STL, Caster_Wheel_Holder_Mirror.STL]
2019-12-13 new caster sldprt
    [Caster_Wheel.SLDPRT, Caster_Wheel_Holder.SLDPRT, Caster_Wheel_Holder_Mirror.SLDPRT]
2019-12-14 manual bike control complete can control servos and motors
2019-12-14 Tail lights work, brake lights almost work.
2019-12-14 More debugging, still having problems comparing time stamps.
    [board_params.h, main.c, mpu.c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]
2019-12-15 More implementation including new PID.c/ PID.h
2019-12-15 fixed bug to do wth multiple instances of app_timer_init
    [board_params.h, main.c, mpu.c]
2019-12-15 CHanged timer module.
2019-12-15 changed clock prescaler and calibrated gyro reading (i think)
2019-12-15 heading working well, but need to switch computer cus this mouse isnt working
2019-12-16 fixed right hand rule issues and using heading from sensor fusion
    [control.c, main.c, mpu.c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]
2019-12-16 fixed bug so we can now send backward paths in autonomous mode
    [board_params.h]
2019-12-16 added buzzer code, but need more current to make it loud
    [board_params.h, main.c, setup.h]
2019-12-16 Add files via upload
    Final Flywheel to be printed.
    [Final_Flywheel.SLDPRT]
2019-12-16 changed the way we send angles for the path plan to the buckler
2019-12-17 no buzzer but everything else ready for demo
    [main.c]
2019-12-18 added readme for accelerometer and final flywheel stl
2019-12-18 new printing file for flywheel
    [Final_Flywheel.stl]
